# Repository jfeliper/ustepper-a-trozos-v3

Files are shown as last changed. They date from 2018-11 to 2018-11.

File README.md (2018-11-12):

# ustepper-a-trozos v3
Es una adaptación del ustepper
adaptada a componentes gordos para poder montarlo a mano.
Usa un arduino nano y componentes smd de tamaño 1206, que se pueden soldar incluso aunque nos vaya fallando la vista.

Esta versión corrige el error de la pista de la NTC que faltaba.
También cambia el direccionamiento del pololu ahora:
STEP es el pin4 del nano
DIR es el pin7
ENA es el pin8 
y las patas par configurar los micropasos son ahora las 11, 12 y 13
He añadido unos leds smd para ver el estado de dichos micropaos.

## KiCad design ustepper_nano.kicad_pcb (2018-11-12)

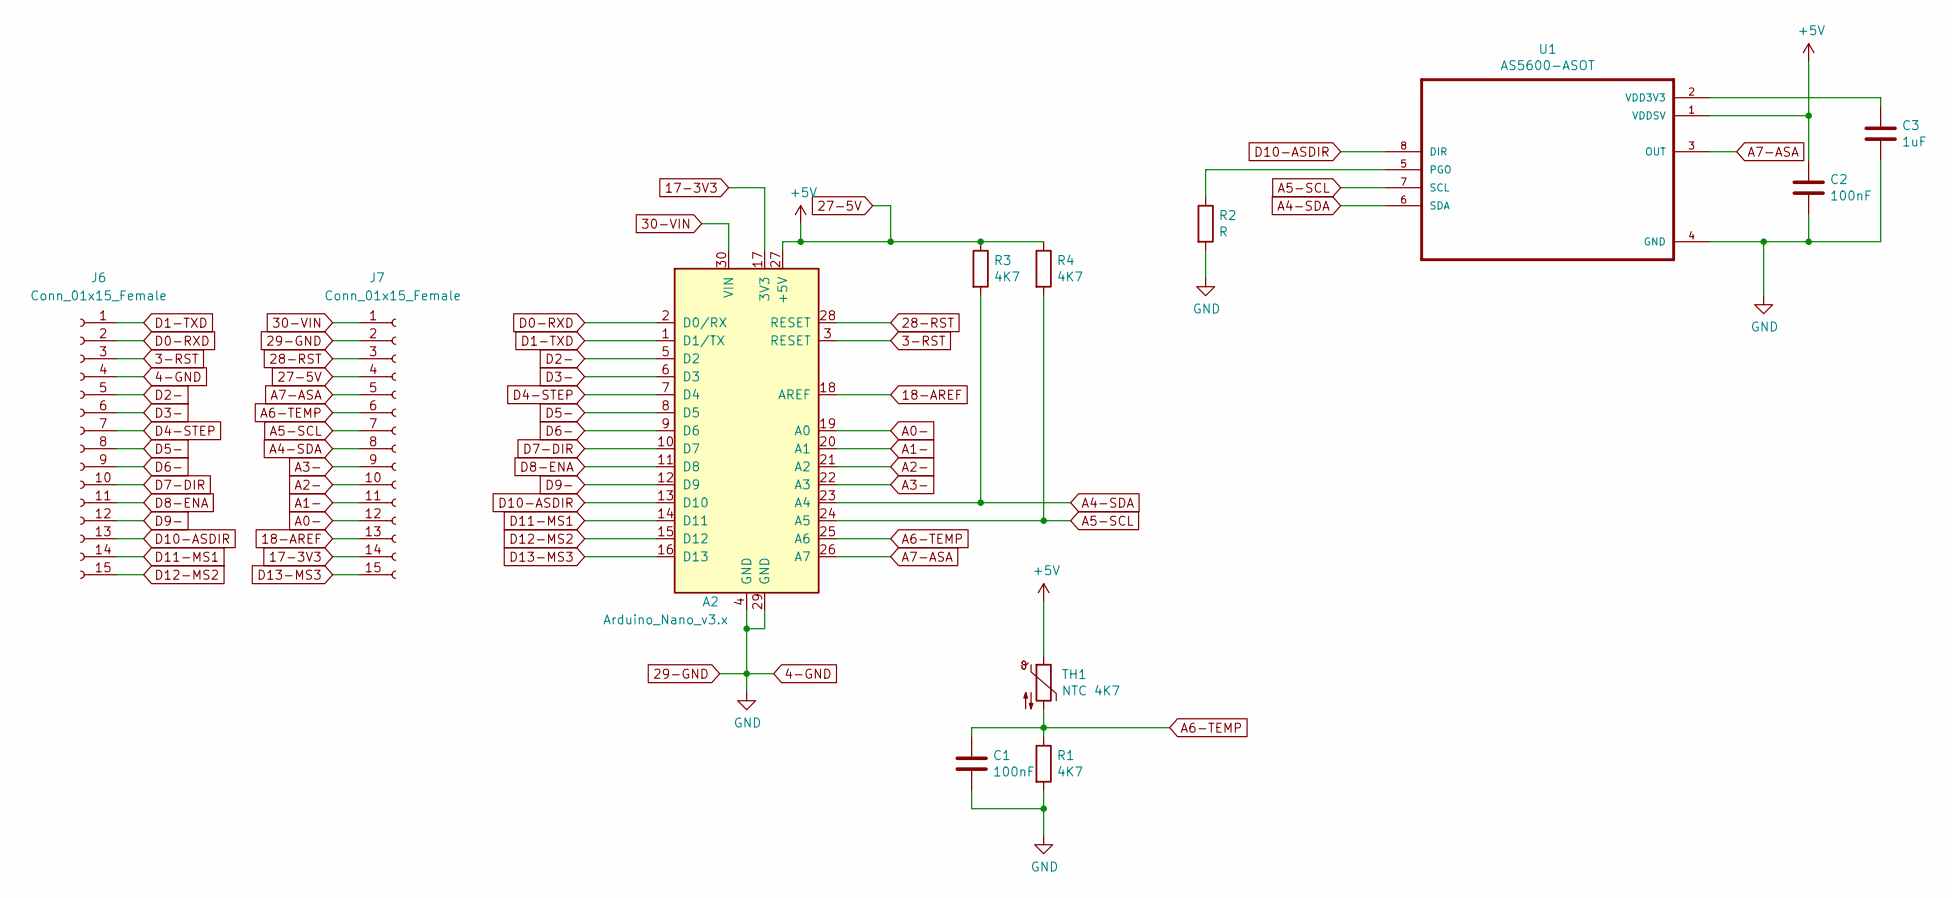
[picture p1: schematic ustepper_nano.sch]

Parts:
A2: Arduino_Nano_v3.x; Arduino_Nano
C1, C2: 100nF; C_1206_3216Metric_Pad1.42x1.75mm_HandSolder
C3: 1uF; C_1206_3216Metric_Pad1.42x1.75mm_HandSolder
J6, J7: Conn_01x15_Female; PinSocket_1x15_P2.54mm_Vertical
R1, R3, R4: 4K7; R_1206_3216Metric_Pad1.42x1.75mm_HandSolder
R2: R; R_1206_3216Metric_Pad1.42x1.75mm_HandSolder
TH1: NTC 4K7; R_1206_3216Metric_Pad1.42x1.75mm_HandSolder
U1: AS5600-ASOT; SOIC-8_3.9x4.9mm_P1.27mm

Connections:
3-RST: A2.3 (RESET), J6.3
17-3V3: A2.17 (3V3), J7.14
18-AREF: A2.18 (AREF), J7.13
27-5V: A2.27 (+5V), C2.1, J7.4, R3.1, R4.1, TH1.1, U1.1 (VDDSV)
28-RST: A2.28 (RESET), J7.3
29-GND: A2.4 (GND), A2.29 (GND), C1.2, C2.2, C3.2, J6.4, J7.2, R1.2, R2.2, U1.4 (GND)
30-VIN: A2.30 (VIN), J7.1
A0-: A2.19 (A0), J7.12
A1-: A2.20 (A1), J7.11
A2-: A2.21 (A2), J7.10
A3-: A2.22 (A3), J7.9
A4-SDA: A2.23 (A4), J7.8, R3.2, U1.6 (SDA)
A5-SCL: A2.24 (A5), J7.7, R4.2, U1.7 (SCL)
A6-TEMP: A2.25 (A6), C1.1, J7.6, R1.1, TH1.2
A7-ASA: A2.26 (A7), J7.5, U1.3 (OUT)
D0-RXD: A2.2 (D0/RX), J6.2
D1-TXD: A2.1 (D1/TX), J6.1
D2-: A2.5 (D2), J6.5
D3-: A2.6 (D3), J6.6
D4-STEP: A2.7 (D4), J6.7
D5-: A2.8 (D5), J6.8
D6-: A2.9 (D6), J6.9
D7-DIR: A2.10 (D7), J6.10
D8-ENA: A2.11 (D8), J6.11
D9-: A2.12 (D9), J6.12
D10-ASDIR: A2.13 (D10), J6.13, U1.8 (DIR)
D11-MS1: A2.14 (D11), J6.14
D12-MS2: A2.15 (D12), J6.15
D13-MS3: A2.16 (D13), J7.15
unnamed: C3.1, U1.2 (VDD3V3)
unnamed: R2.1, U1.5 (PGO)

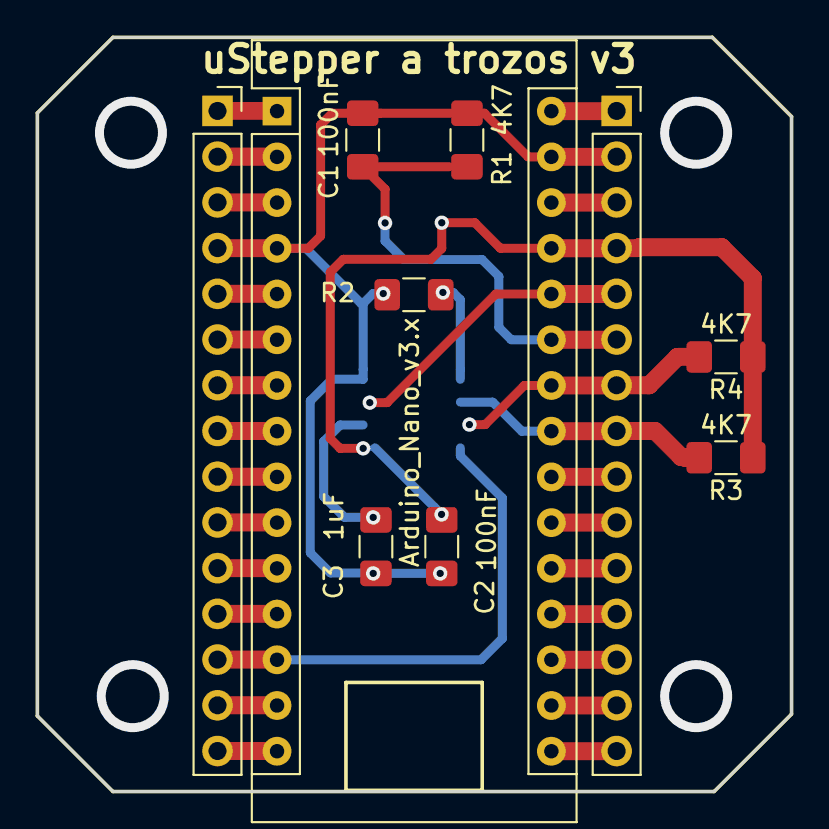
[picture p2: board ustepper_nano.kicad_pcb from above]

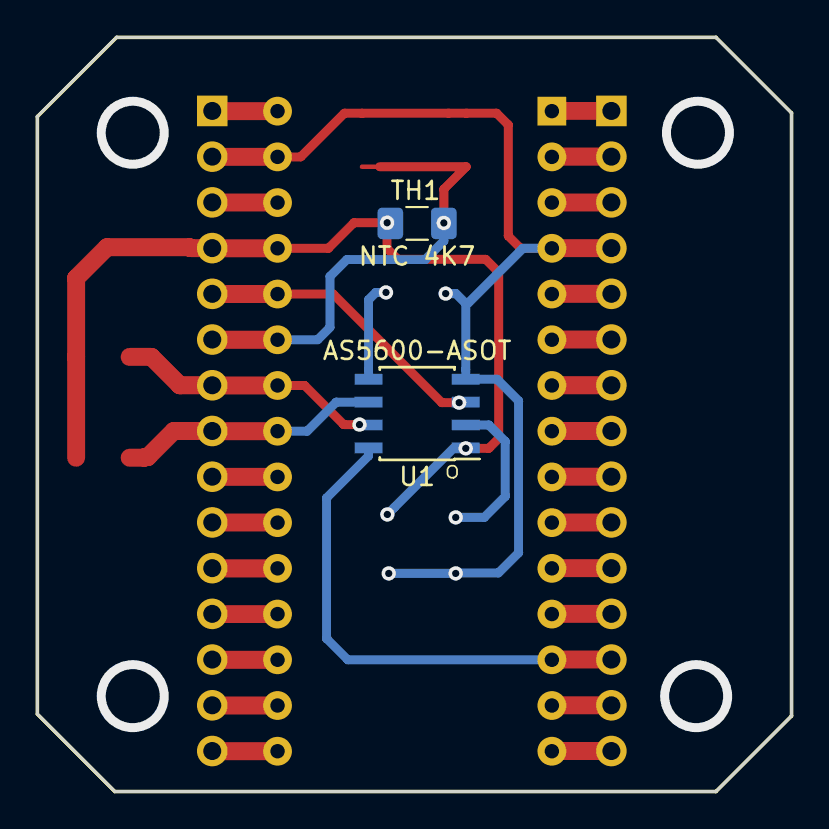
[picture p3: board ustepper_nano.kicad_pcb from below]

Board: 2 copper layers, 41.9 x 41.9 mm, 12 parts (2 on the bottom side), 31 nets.

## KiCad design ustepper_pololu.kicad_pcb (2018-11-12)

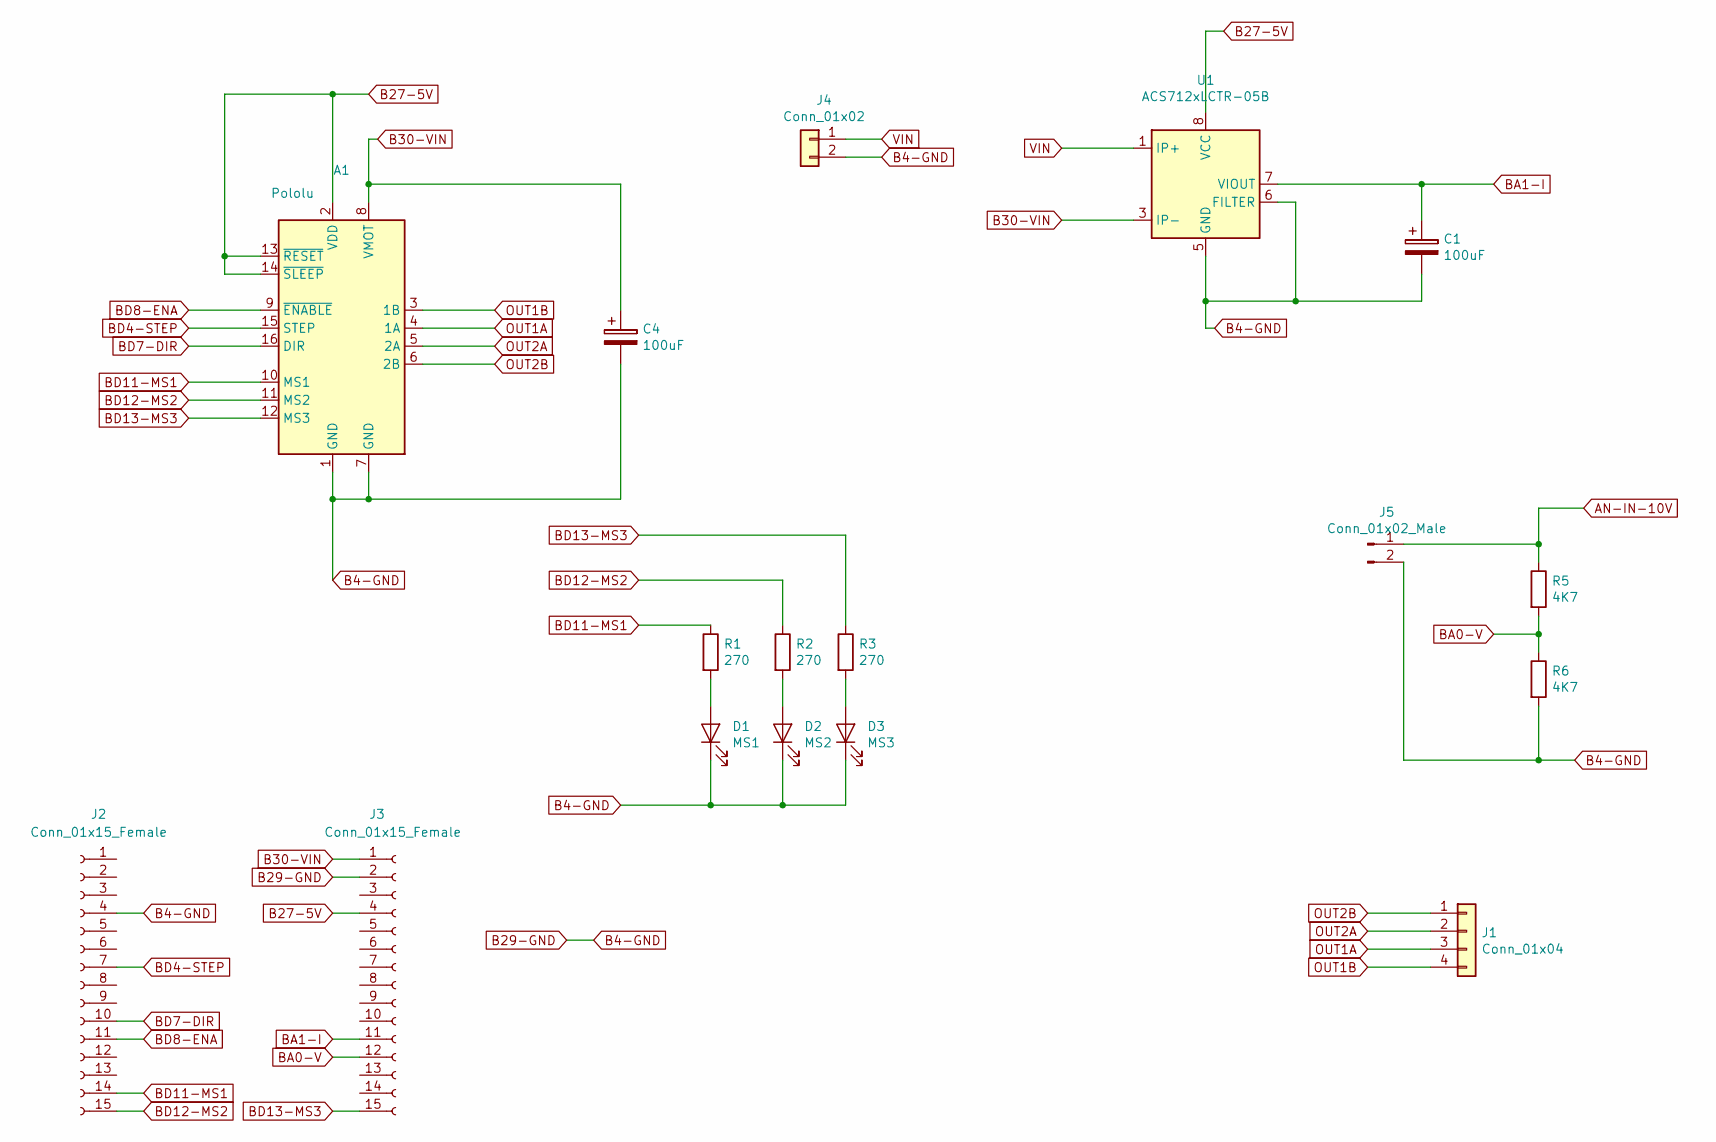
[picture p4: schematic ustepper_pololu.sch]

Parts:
A1: Pololu; Pololu_Breakout-16_15.2x20.3mm
C1: 100uF; C_1206_3216Metric_Pad1.42x1.75mm_HandSolder
C4: 100uF; CP_Radial_D6.3mm_P2.50mm
D1: MS1; LED_1206_3216Metric_Pad1.42x1.75mm_HandSolder
D2: MS2; LED_1206_3216Metric_Pad1.42x1.75mm_HandSolder
D3: MS3; LED_1206_3216Metric_Pad1.42x1.75mm_HandSolder
J1: Conn_01x04; PinHeader_1x04_P2.54mm_Vertical
J2, J3: Conn_01x15_Female; PinHeader_1x15_P2.54mm_Vertical
J4: Conn_01x02; PhoenixContact_MSTBA_2,5_2-G_1x02_P5.00mm_Horizontal
J5: Conn_01x02_Male; PinHeader_1x02_P2.54mm_Vertical
R1, R2, R3: 270; R_1206_3216Metric_Pad1.42x1.75mm_HandSolder
R5, R6: 4K7; R_1206_3216Metric_Pad1.42x1.75mm_HandSolder
U1: ACS712xLCTR-05B; SOIC-8_3.9x4.9mm_P1.27mm

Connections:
AN-IN-10V: J5.1, R5.1
B27-5V: A1.2 (VDD), A1.13 (~RESET), A1.14 (~SLEEP), J3.4, U1.8 (VCC)
B29-GND: A1.1 (GND), A1.7 (GND), C1.2, C4.2, D1.1 (K), D2.1 (K), D3.1 (K), J2.4, J3.2, J4.2, J5.2, R6.2, U1.5 (GND), U1.6 (FILTER)
B30-VIN: A1.8 (VMOT), C4.1, J3.1, U1.3 (IP-), U1.4 (IP-)
BA0-V: J3.12, R5.2, R6.1
BA1-I: C1.1, J3.11, U1.7 (VIOUT)
BD4-STEP: A1.15 (STEP), J2.7
BD7-DIR: A1.16 (DIR), J2.10
BD8-ENA: A1.9 (~ENABLE), J2.11
BD11-MS1: A1.10 (MS1), J2.14, R1.1
BD12-MS2: A1.11 (MS2), J2.15, R2.1
BD13-MS3: A1.12 (MS3), J3.15, R3.1
unnamed: D1.2 (A), R1.2
unnamed: D2.2 (A), R2.2
unnamed: D3.2 (A), R3.2
OUT1A: A1.4 (1A), J1.3
OUT1B: A1.3 (1B), J1.4
OUT2A: A1.5 (2A), J1.2
OUT2B: A1.6 (2B), J1.1
VIN: J4.1, U1.1 (IP+), U1.2 (IP+)

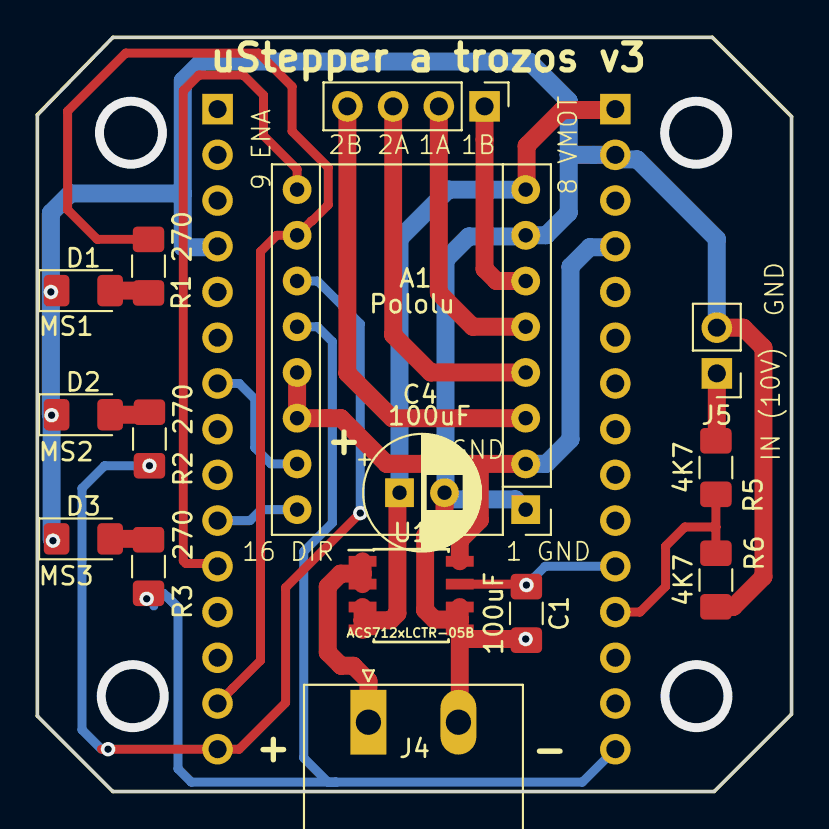
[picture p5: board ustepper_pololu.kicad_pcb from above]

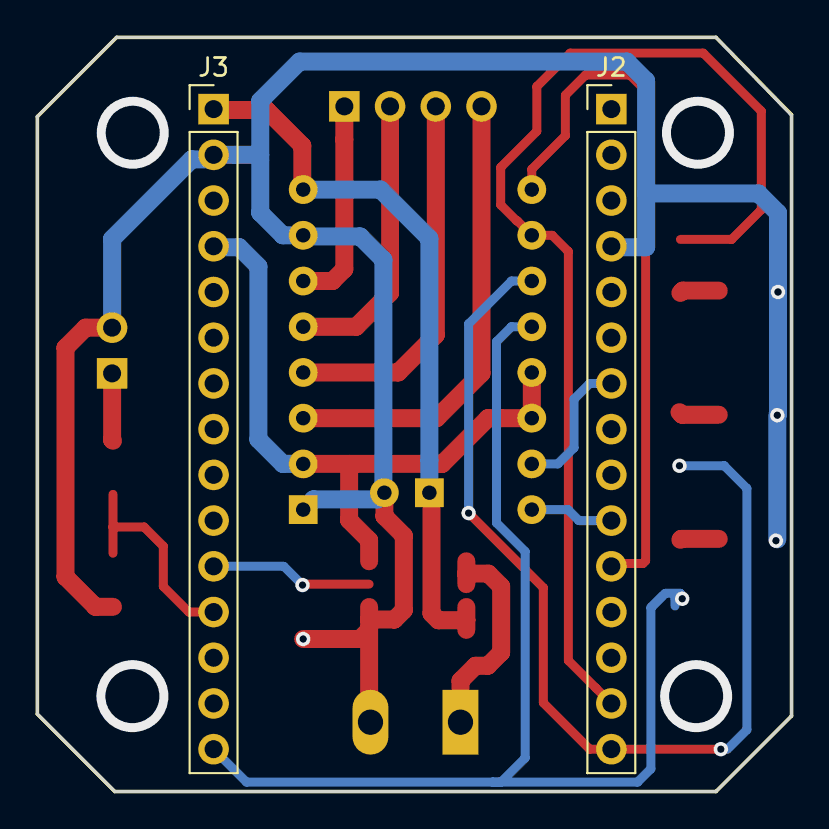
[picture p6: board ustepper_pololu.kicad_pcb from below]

Board: 2 copper layers, 41.9 x 41.9 mm, 17 parts (2 on the bottom side), 20 nets.
